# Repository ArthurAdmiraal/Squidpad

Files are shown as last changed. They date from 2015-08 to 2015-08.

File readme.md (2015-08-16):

# Squidpad
### About
The squidpad is a Slim Quality Uncostly Intuitive Drawing Pad. These are all the source files. This is an open project, which I'm documenting on [hackaday.io](https://hackaday.io/project/7153-squidpad).

### Repository structure
All design files go in the `Project` folder. Any files just made for documentation, such as a diagram in GeoGebra, can be found in the `Documentation` folder.

In both folders, the `Design files` folder contains source files. In the `Documentation` folder, any diagrams of pictures are just in the top-level folder. In the `Project` folder however, files generated using the design software, such as gerber files, can be found in the `Manifacturing` folder. People that just want to have a look at the board can find pdf's and OSHpark renders in the `Easily viewable` folder.

### License
All files in the `Project` folder are licensed under the [Creative Commons Attribution-NonCommercial-ShareAlike 4.0 International](http://creativecommons.org/licenses/by-nc-sa/4.0/) license. Everything in the `Documentation` folder can be used under the [Creative Commons Attribution-ShareAlike 4.0 International](http://creativecommons.org/licenses/by-sa/4.0/) license.

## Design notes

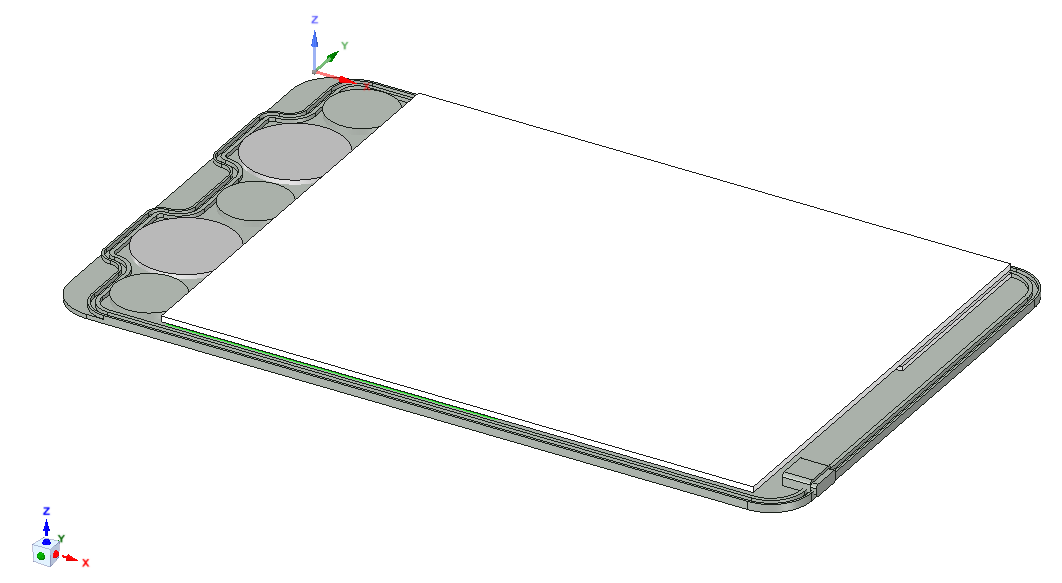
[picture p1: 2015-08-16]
Project/Easily viewable/MockupMechanical.png

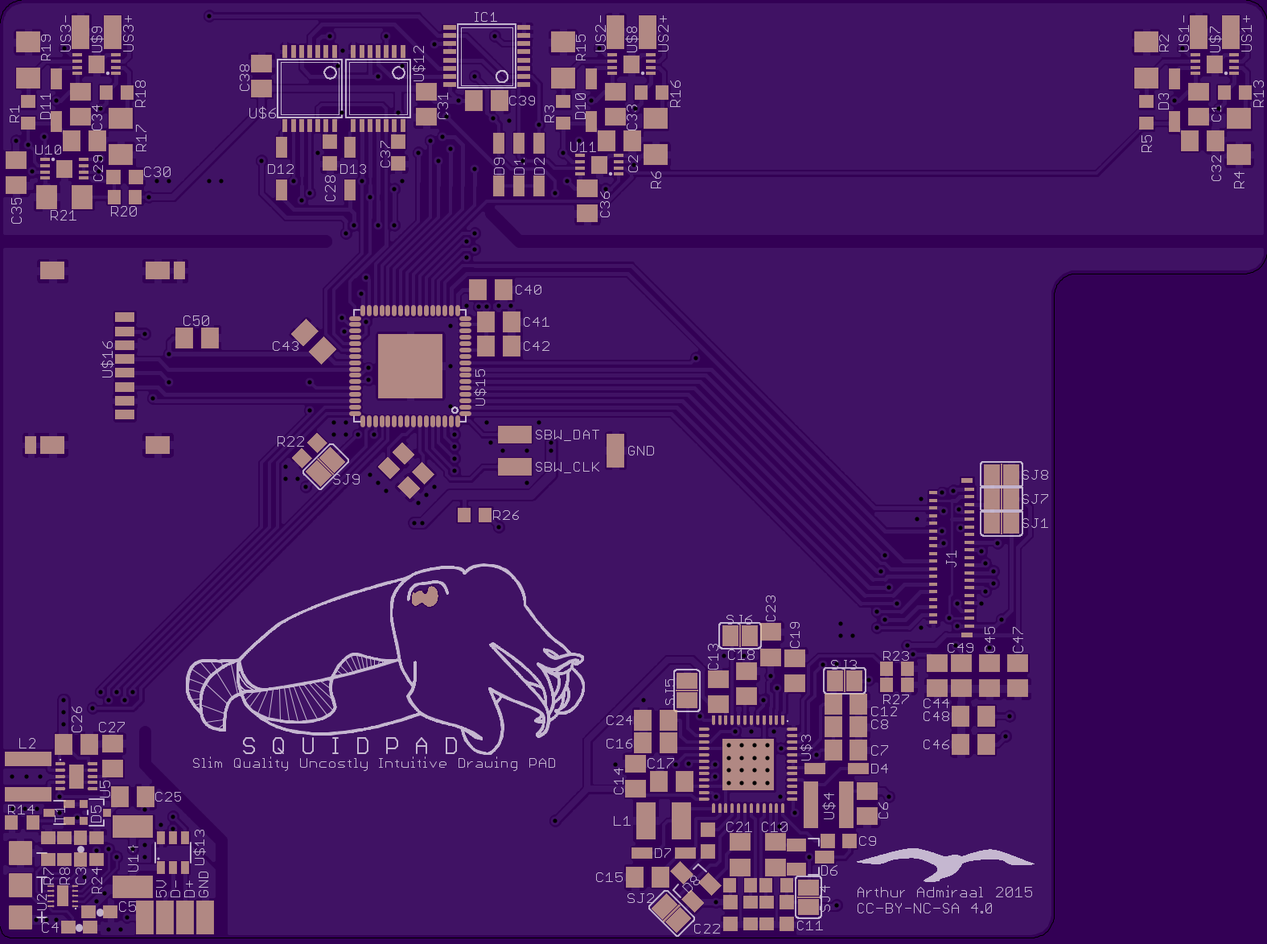
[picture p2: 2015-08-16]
Project/Easily viewable/SquidpadOSHparkRenderTop.png

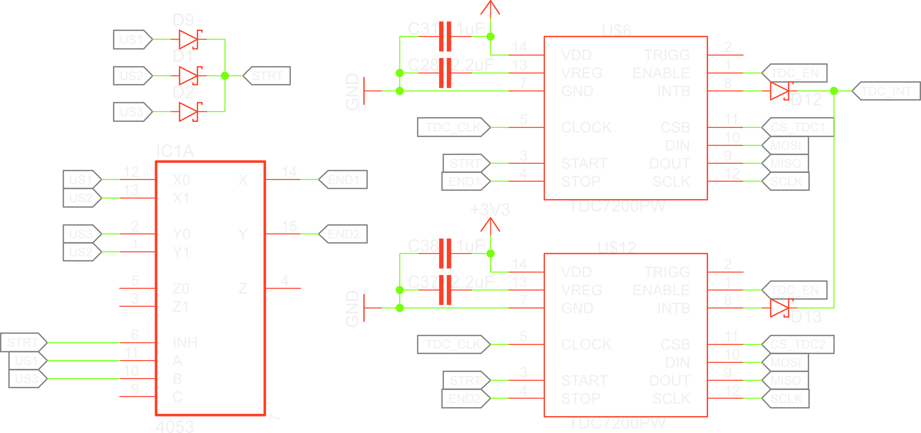
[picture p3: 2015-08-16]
Documentation/MicSwitching.png

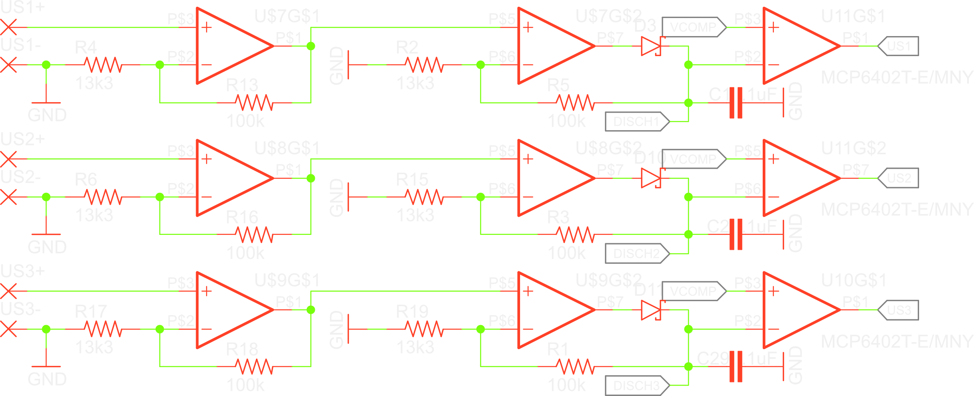
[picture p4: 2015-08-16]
Documentation/MicAmp.png

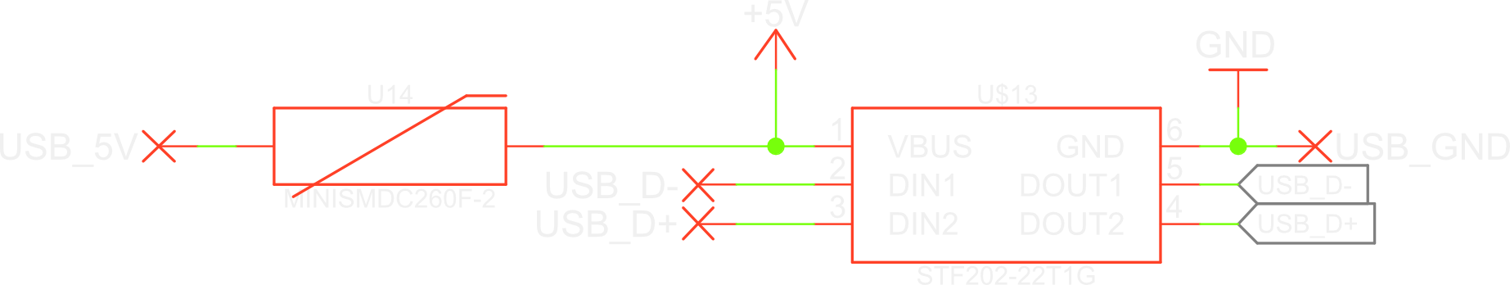
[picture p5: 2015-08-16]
Documentation/InputProtection.png

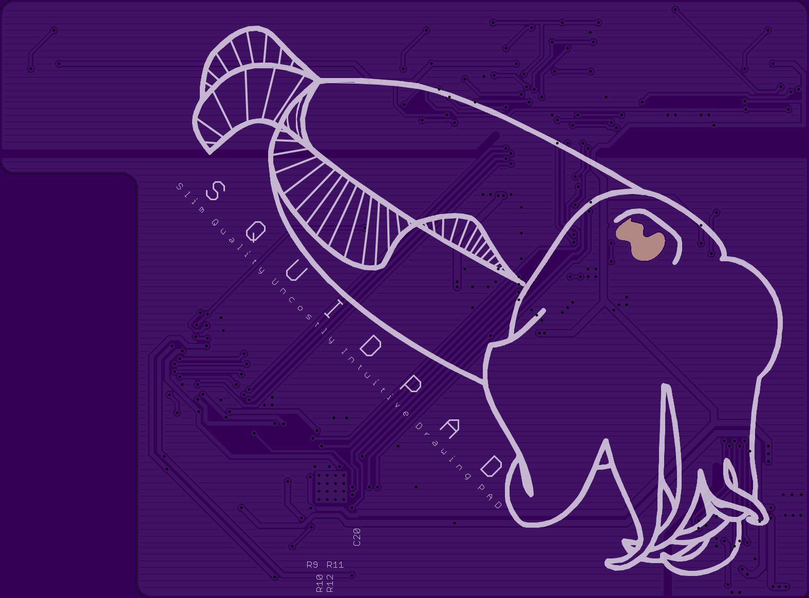
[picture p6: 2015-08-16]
Project/Easily viewable/SquidpadOSHparkRenderBottom.png

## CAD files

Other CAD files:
Documentation/Design files/MaterialsTest.blend

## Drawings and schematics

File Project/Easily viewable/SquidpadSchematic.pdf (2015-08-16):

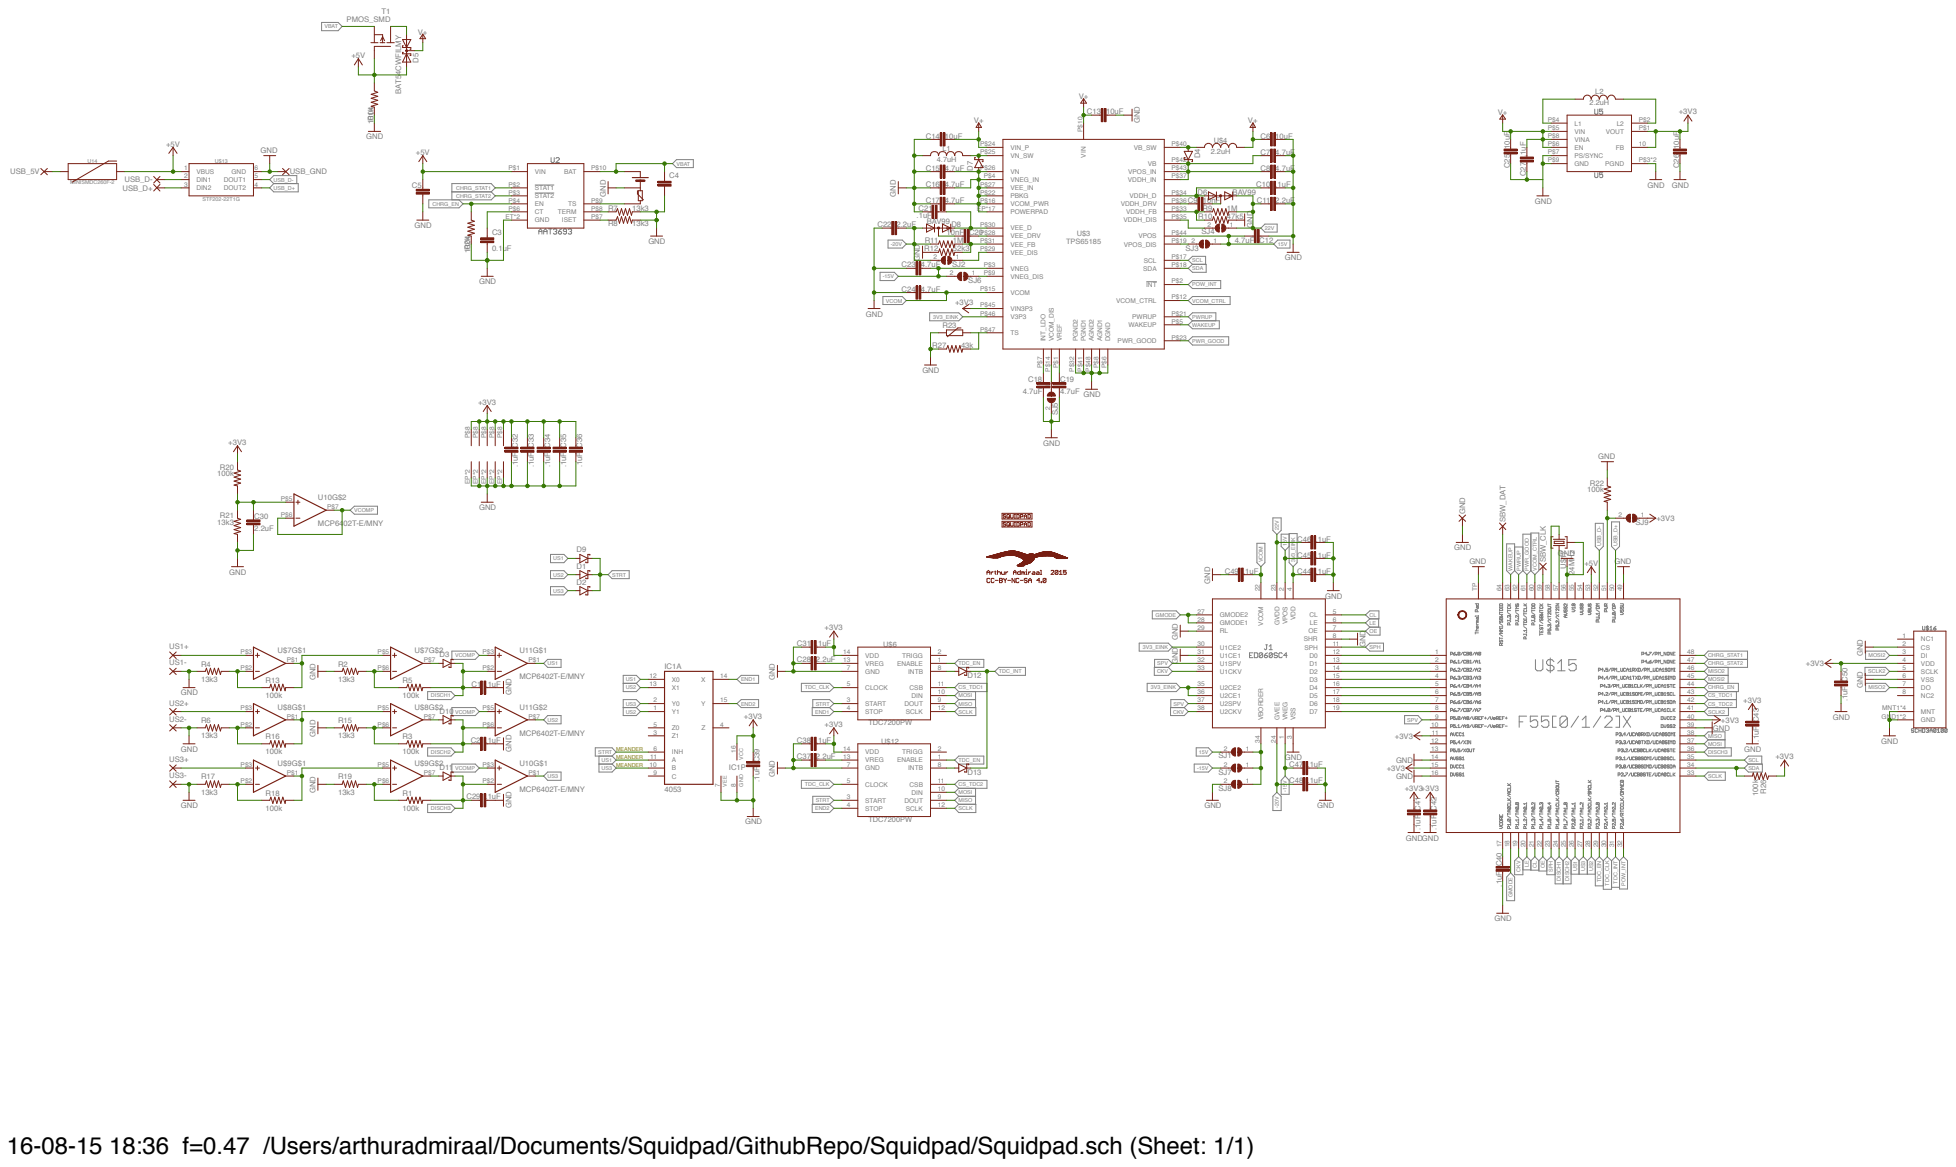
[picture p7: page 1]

16-08-15 18:36 f=0.47 /Users/arthuradmiraal/Documents/Squidpad/GithubRepo/Squidpad/Squidpad.sch (Sheet: 1/1)

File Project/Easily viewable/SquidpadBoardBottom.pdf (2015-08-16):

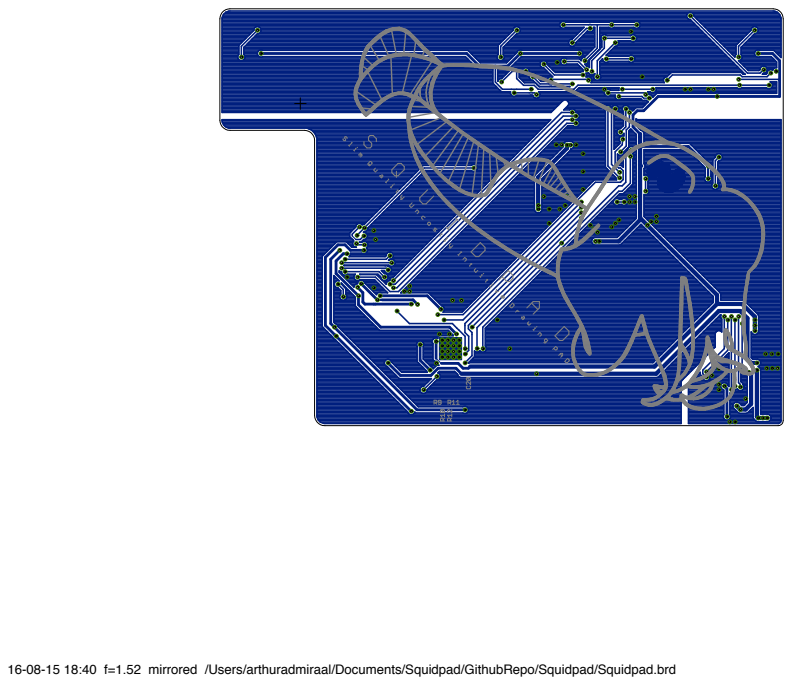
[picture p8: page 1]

16-08-15 18:40 f=1.52 mirrored /Users/arthuradmiraal/Documents/Squidpad/GithubRepo/Squidpad/Squidpad.brd

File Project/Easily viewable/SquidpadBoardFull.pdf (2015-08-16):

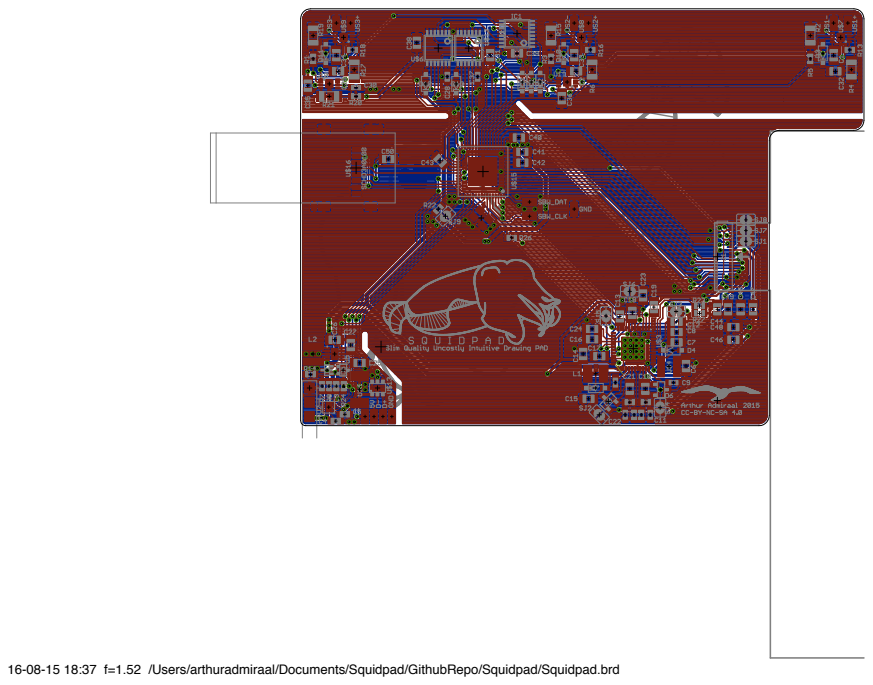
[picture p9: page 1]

16-08-15 18:37 f=1.52 /Users/arthuradmiraal/Documents/Squidpad/GithubRepo/Squidpad/Squidpad.brd

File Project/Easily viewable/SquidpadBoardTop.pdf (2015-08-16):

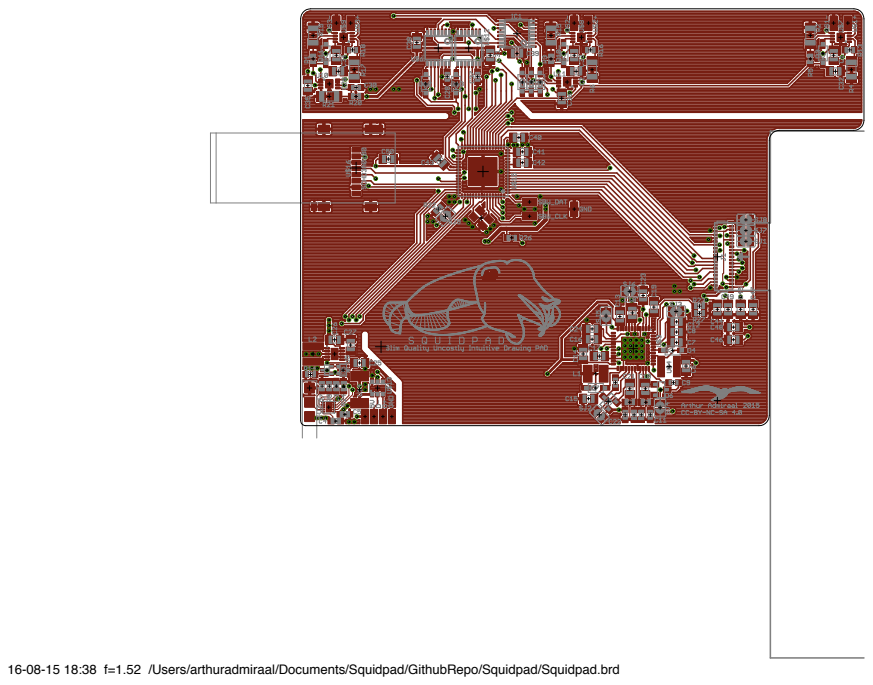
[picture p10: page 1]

16-08-15 18:38 f=1.52 /Users/arthuradmiraal/Documents/Squidpad/GithubRepo/Squidpad/Squidpad.brd

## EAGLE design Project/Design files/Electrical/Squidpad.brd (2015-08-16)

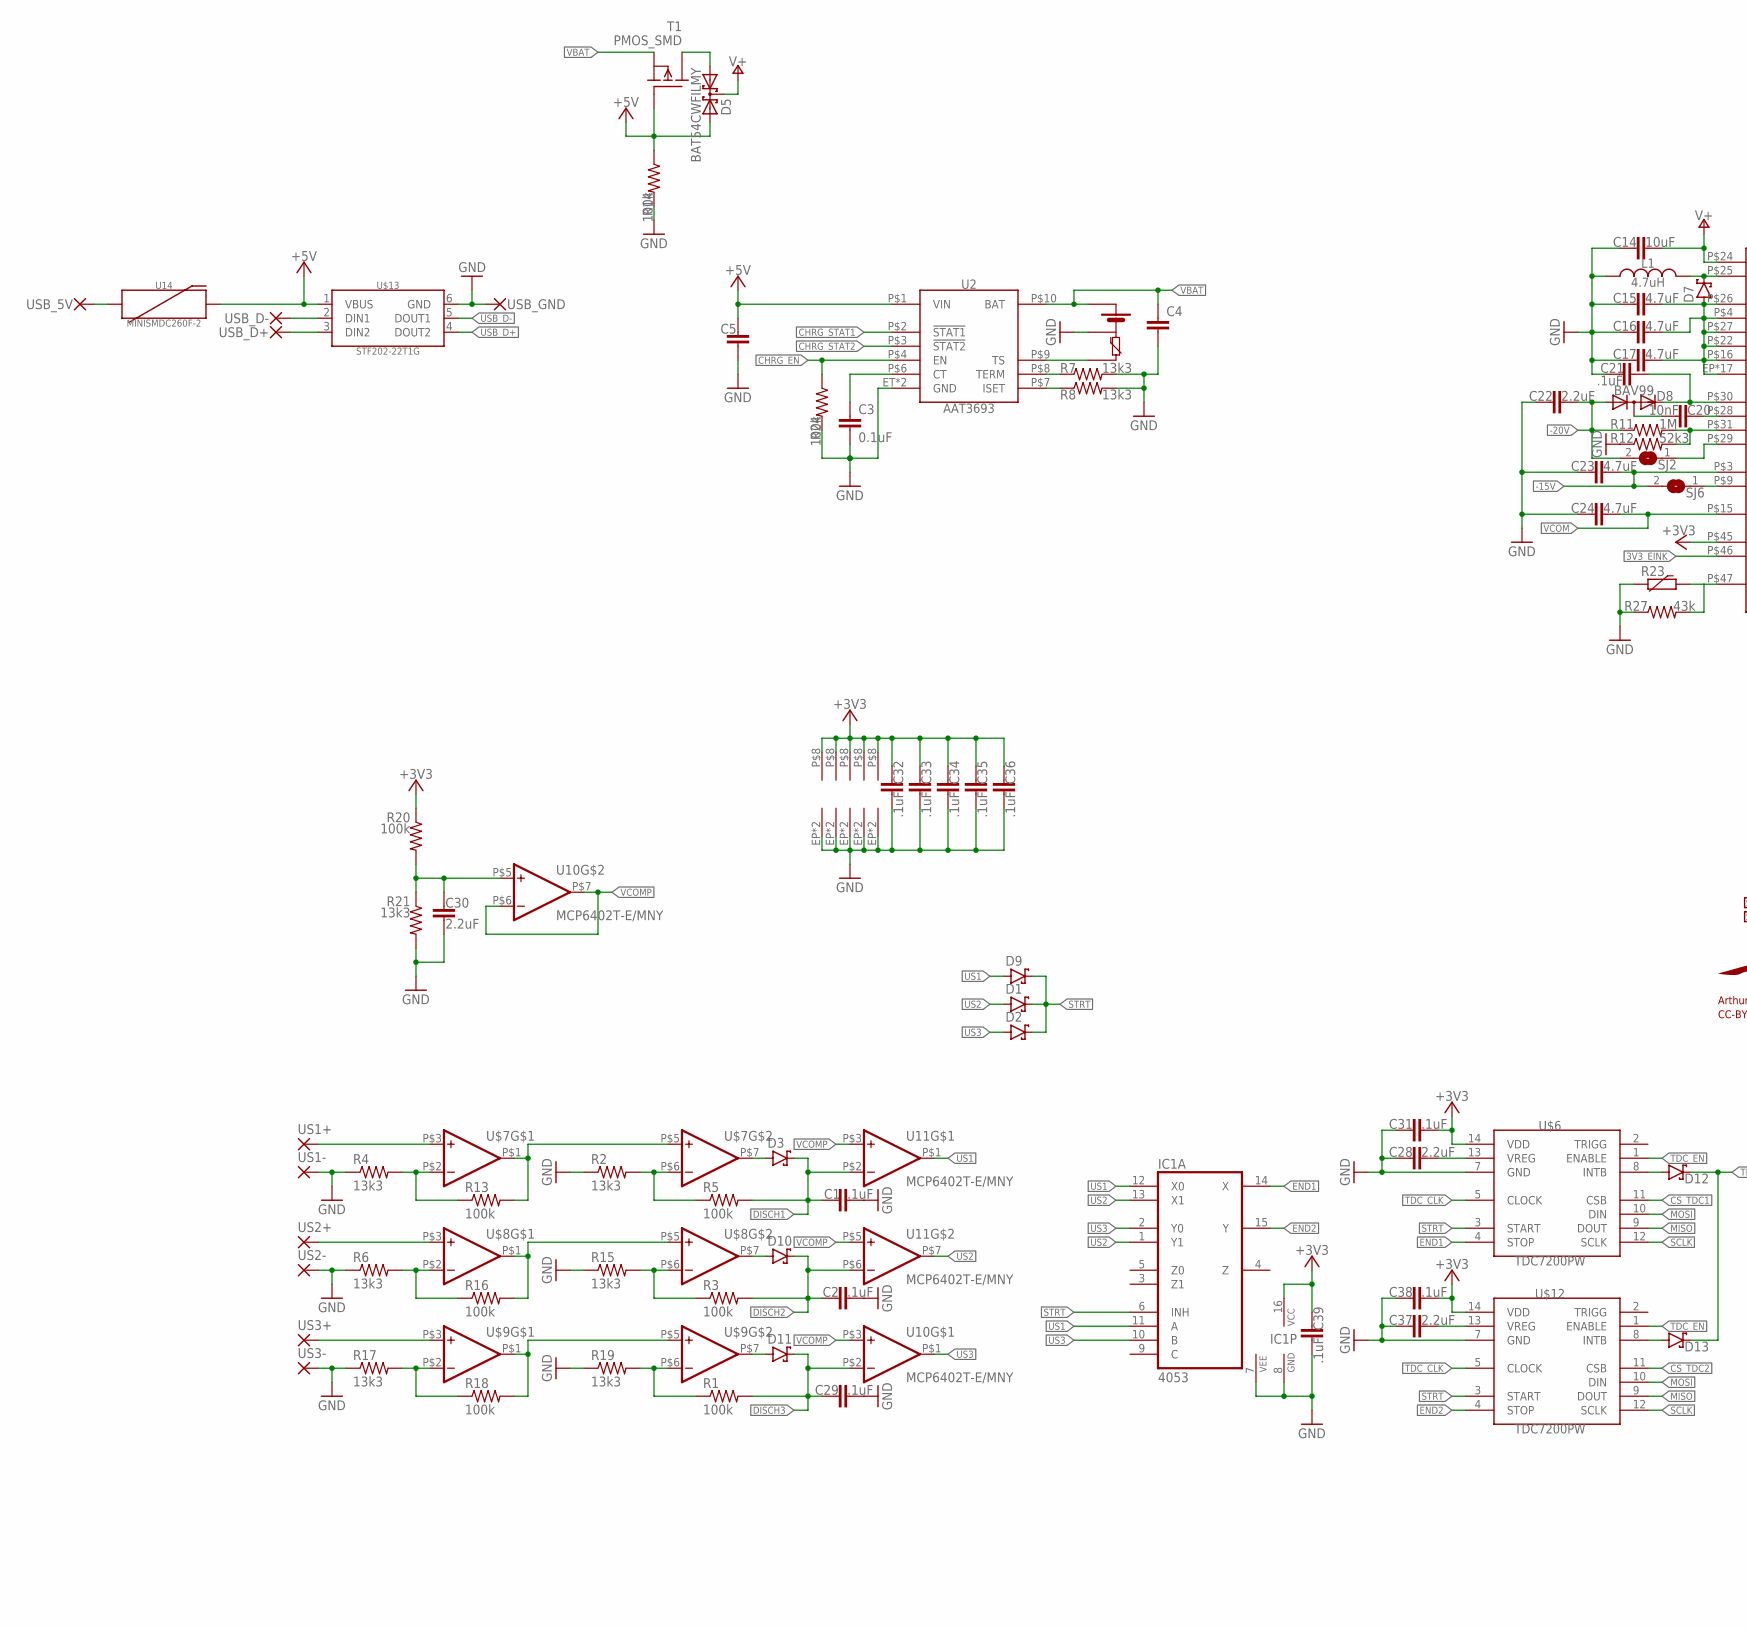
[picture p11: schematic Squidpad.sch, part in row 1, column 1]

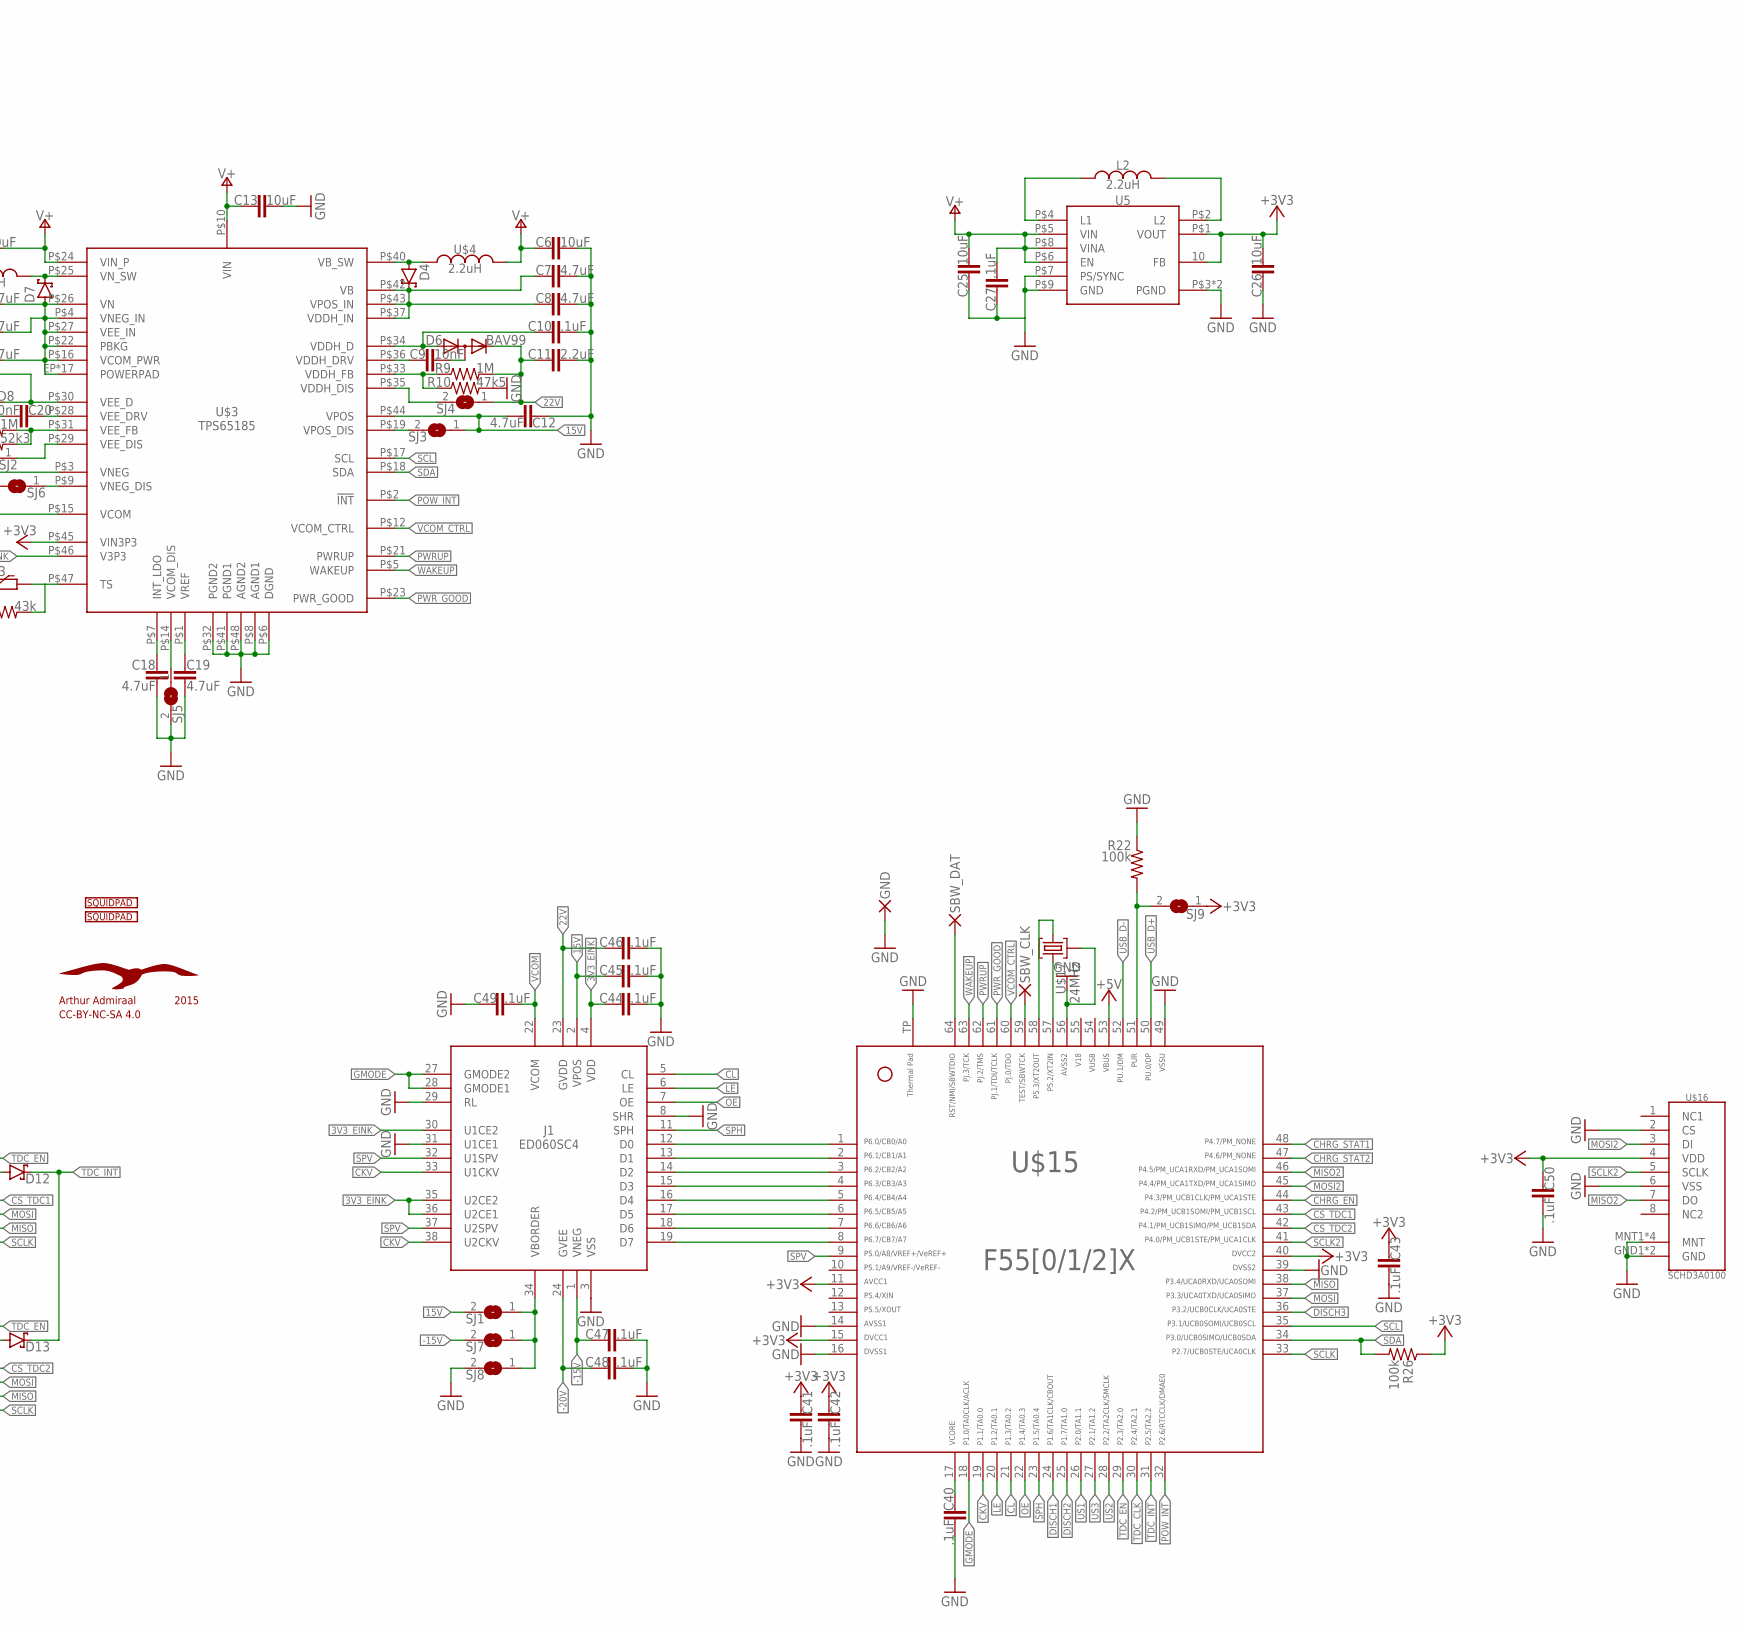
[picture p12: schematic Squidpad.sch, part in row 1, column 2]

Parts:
C1, C2, C10, C21, C27, C29, C31, C32, C33, C34, C35, C36, C38, C39, C40, C41, C42, C43, C44, C45, C46, C47, C48, C49, C50: .1uF; C0805K
C3: 0.1uF; 0603-CAP
C4, C5: CAP0603-CAP; 0603-CAP
C6, C13, C14, C25, C26: 10uF; C0805K
C7, C8, C12, C15, C16, C17, C18, C19, C23, C24: 4.7uF; C0805K
C9, C20: 10nF; C0603K
C11, C22, C28, C30, C37: 2.2uF; C0603K
D1, D2, D3, D4, D7, D9, D10, D11, D12, D13: MBR130T3G; SOD123
D5: BAT54CWFILMY; SOT323
D6, D8: BAV99; SOT23
GND: SMD2; SMD1,27-2,54
IC1: 4053; TSSOP16
J1: ED060SC4; FH26-39S-0.3SHW(05)
L1: 4.7uH; LQH44P
L2: 2.2uH; NR4012
R1, R3, R5, R13, R14, R16, R18, R20, R22, R24, R26: 100k; R0603
R2, R4, R6, R15, R17, R19, R21: 13k3; R1206
R7, R8: 13k3; R0603
R9, R11: 1M; R0603
R10: 47k5; R0603
R12: 52k3; R0603
R23: R-EU_R0603; R0603
R27: 43k; R0603
SBW_CLK: SMD2; SMD1,27-2,54
SBW_DAT: SMD2; SMD1,27-2,54
SJ1, SJ2, SJ3, SJ4, SJ5, SJ6, SJ7, SJ8, SJ9: SJ
T1: PMOS_SMD; SOT323R_INFINEON
U2: AAT3693; TDFN14
U5: TPS63031; R-PWSON-N10
U10, U11: MCP6402T-E/MNY; TFDN8
U14: MINISMDC260F-2
U$1: IPOD_NANO_5_BATTERY
U$2: SQUIDPAD_LOGOSQUIDPAD_LOGO_SMALL; SQUIDPAD_LOGO_LOWPOLY_SMALL
U$3: TPS65185; VQFN48
U$4: 2.2uH; NR4012
U$5: SQUIDPAD_LOGOSQUIDPAD_LOGO; SQUIDPAD_LOGO_LOWPOLY
U$6, U$12: TDC7200PW; TSSOP14
U$7, U$8, U$9: MCP6402T-E/MNY; TFDN8
U$10: AALECTRONICS_SEAGULL
U$13: STF202-22T1G; SOT23-6
U$15: F55[0/1/2]X---RGC64; RGC64
U$16: SCHD3A0100
U$17: 24MHz; TSX-3225
US1+, US1-, US2+, US2-, US3+, US3-: SMD2; SMD1,27-2,54
USB_5V: SMD2; SMD1,27-2,54
USB_D+: SMD2; SMD1,27-2,54
USB_D-: SMD2; SMD1,27-2,54
USB_GND: SMD2; SMD1,27-2,54

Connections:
3V3: C6.1, C13.1, C14.2, C25.2, C27.2, D5.3 (C), U5.P$5 (VIN), U5.P$6 (EN), U5.P$8 (VINA), U$3.P$10 (VIN), U$3.P$24 (VIN_P), U$4.P$2
3V3_EINK: C44.1, J1.4 (VDD), J1.30 (U1CE2), J1.35 (U2CE2), J1.36 (U2CE1), U$3.P$46 (V3P3)
15V: C12.2, C45.1, J1.2 (VPOS), SJ1.2, SJ3.1, U$3.P$44 (VPOS)
22V: C11.1, C46.1, D6.2 (C), J1.23 (GVDD), R9.2, SJ4.1
54: U$15.54
55: U$15.55
+3V3: C26.2, C31.2, C32.1, C33.1, C34.1, C35.1, C36.1, C38.2, C39.1, C41.1, C42.1, C43.1, C50.1, IC1.16 (VCC), R20.1, R26.1, SJ9.1, U5.10 (FB), U5.P$1 (VOUT), U10.P$8 (V+), U11.P$8 (V+), U$3.P$45 (VIN3P3), U$6.14 (VDD), U$7.P$8 (V+), U$8.P$8 (V+), U$9.P$8 (V+), U$12.14 (VDD), U$15.11, U$15.15, U$15.40, U$16.4 (VDD)
+5V: C5.1, D5.2 (A2), R14.1, T1.1 (G), U2.P$1 (VIN), U14.P$2, U$13.1 (VBUS), U$15.53
-15V: C23.2, C47.1, J1.1 (VNEG), SJ6.2, SJ7.2, U$3.P$3 (VNEG)
-20V: C22.2, C48.1, D8.1 (A), J1.24 (GVEE), R11.1, SJ2.2
CHRG_EN: R24.1, U2.P$4 (EN), U$15.44
CHRG_STAT1: U2.P$2 (!STAT1), U$15.48
CHRG_STAT2: U2.P$3 (!STAT2), U$15.47
CKV: J1.33 (U1CKV), J1.38 (U2CKV), U$15.19
CL: J1.5 (CL), U$15.21
CS_TDC1: U$6.11 (CSB), U$15.43
CS_TDC2: U$12.11 (CSB), U$15.42
D0: J1.12 (D0), U$15.1
D1: J1.13 (D1), U$15.2
D2: J1.14 (D2), U$15.3
D3: J1.15 (D3), U$15.4
D4: J1.16 (D4), U$15.5
D5: J1.17 (D5), U$15.6
D6: J1.18 (D6), U$15.7
D7: J1.19 (D7), U$15.8
DISCH1: C1.1, D3.1 (C), R5.2, U11.P$2 (-IN), U$15.24
DISCH2: C2.1, D10.1 (C), R3.2, U11.P$6 (-IN), U$15.25
DISCH3: C29.1, D11.1 (C), R1.2, U10.P$2 (-IN), U$15.36
END1: IC1.14 (X), U$6.4 (STOP)
END2: IC1.15 (Y), U$12.4 (STOP)
GMODE: J1.27 (GMODE2), J1.28 (GMODE1), U$15.18
GND: C1.2, C2.2, C3.2, C4.2, C5.2, C6.2, C7.2, C8.2, C10.2, C11.2, C12.1, C13.2, C14.1, C15.1, C16.1, C17.1, C18.1, C19.1, C21.1, C22.1, C23.1, C24.1, C25.1, C26.1, C27.1, C28.1, C29.2, C30.2, C31.1, C32.2, C33.2, C34.2, C35.2, C36.2, C37.1, C38.1, C39.2, C40.2, C41.2, C42.2, C43.2, C44.2, C45.2, C46.2, C47.2, C48.2, C49.1, C50.2, GND.1, IC1.7 (VEE), IC1.8 (GND), J1.3 (VSS), J1.8 (SHR), J1.29 (RL), J1.31 (U1CE1), L1.P$1, R2.1, R4.1, R6.1, R7.2, R8.2, R10.2, R12.1, R14.2, R15.1, R17.1, R19.1, R21.2, R22.1, R23.1, R24.2, R27.1, SJ5.2, SJ8.2, U2.ET (GND), U2.P$5 (GND), U5.P$3 (PGND), U5.P$7 (PS/SYNC), U5.P$9 (GND), U5.POWERPAD (PGND), U10.EP (V-), U10.P$4 (V-), U11.EP (V-), U11.P$4 (V-), U$1.P- (BATTERY-), U$3.P$6 (DGND), U$3.P$8 (AGND1), U$3.P$32 (PGND2), U$3.P$41 (PGND1), U$3.P$48 (AGND2), U$6.7 (GND), U$7.EP (V-), U$7.P$4 (V-), U$8.EP (V-), U$8.P$4 (V-), U$9.EP (V-), U$9.P$4 (V-), U$12.7 (GND), U$13.6 (GND), U$15.14, U$15.16, U$15.39, U$15.49, U$15.56, U$15.TP, U$16.2 (CS), U$16.6 (VSS), U$16.GND1 (GND), U$16.GND2 (GND), U$16.MNT1 (MNT), U$16.MNT2 (MNT), U$16.MNT3 (MNT), U$16.MNT4 (MNT), U$17.2, U$17.3 (2), US1-.1, US2-.1, US3-.1, USB_GND.1
LE: J1.6 (LE), U$15.20
MISO: U$6.9 (DOUT), U$12.9 (DOUT), U$15.38
MISO2: U$15.46, U$16.7 (DO)
MOSI: U$6.10 (DIN), U$12.10 (DIN), U$15.37
MOSI2: U$15.45, U$16.3 (DI)
unnamed: U$7.P$3 (+IN), US1+.1
unnamed: R2.2, R5.1, U$7.P$6 (-IN)
unnamed: D12.2 (A), U$6.8 (INTB)
unnamed: U$8.P$3 (+IN), US2+.1
unnamed: R6.2, R16.1, U$8.P$2 (-IN)
unnamed: R16.2, U$8.P$1 (OUT), U$8.P$5 (+IN)
unnamed: D4.2 (A), U$3.P$40 (VB_SW), U$4.P$1
unnamed: U2.P$9 (TS), U$1.TH (TEMP)
unnamed: U$13.3 (DIN2), USB_D+.1
unnamed: U$13.2 (DIN1), USB_D-.1
unnamed: U$15.57, U$17.4 (3)
unnamed: R7.1, U2.P$8 (TERM)
unnamed: R8.1, U2.P$7 (ISET)
unnamed: C7.1, C8.1, D4.1 (C), U$3.P$37 (VDDH_IN), U$3.P$42 (VB), U$3.P$43 (VPOS_IN)
unnamed: D3.2 (A), U$7.P$7 (OUT)
unnamed: D13.2 (A), U$12.8 (INTB)
unnamed: C3.1, U2.P$6 (CT)
unnamed: C10.1, D6.1 (A), U$3.P$34 (VDDH_D)
unnamed: D5.1 (A1), T1.3 (D)
unnamed: C9.1, U$3.P$36 (VDDH_DRV)
unnamed: C9.2, D6.3 (AC)
unnamed: R9.1, R10.1, U$3.P$33 (VDDH_FB)
unnamed: C20.2, D8.3 (AC)
unnamed: D7.1 (C), L1.P$2, U$3.P$25 (VN_SW)
unnamed: C15.2, C16.2, C17.2, D7.2 (A), U$3.EP (POWERPAD), U$3.EP1 (POWERPAD), U$3.EP2 (POWERPAD), U$3.EP3 (POWERPAD), U$3.EP4 (POWERPAD), U$3.EP5 (POWERPAD), U$3.EP6 (POWERPAD), U$3.EP7 (POWERPAD), U$3.EP8 (POWERPAD), U$3.EP9 (POWERPAD), U$3.EP10 (POWERPAD), U$3.EP11 (POWERPAD), U$3.EP12 (POWERPAD), U$3.EP13 (POWERPAD), U$3.EP14 (POWERPAD), U$3.EP15 (POWERPAD), U$3.EP16 (POWERPAD), U$3.P$4 (VNEG_IN), U$3.P$16 (VCOM_PWR), U$3.P$22 (PBKG), U$3.P$26 (VN), U$3.P$27 (VEE_IN)
unnamed: C18.2, U$3.P$7 (INT_LDO)
unnamed: C19.2, U$3.P$1 (VREF)
unnamed: C21.2, D8.2 (C), U$3.P$30 (VEE_D)
unnamed: SJ6.1, U$3.P$9 (VNEG_DIS)
unnamed: L2.P$1, U5.P$4 (L1)
unnamed: C20.1, U$3.P$28 (VEE_DRV)
unnamed: R11.2, R12.2, U$3.P$31 (VEE_FB)
unnamed: SJ2.1, U$3.P$29 (VEE_DIS)
unnamed: SJ3.2, U$3.P$19 (VPOS_DIS)
unnamed: SJ4.2, U$3.P$35 (VDDH_DIS)
unnamed: SJ5.1, U$3.P$14 (VCOM_DIS)
unnamed: L2.P$2, U5.P$2 (L2)
unnamed: C28.2, U$6.13 (VREG)
unnamed: R4.2, R13.1, U$7.P$2 (-IN)
unnamed: R13.2, U$7.P$1 (OUT), U$7.P$5 (+IN)
unnamed: R3.1, R15.2, U$8.P$6 (-IN)
unnamed: U14.P$1, USB_5V.1
unnamed: U$9.P$3 (+IN), US3+.1
unnamed: R17.2, R18.1, U$9.P$2 (-IN)
unnamed: R18.2, U$9.P$1 (OUT), U$9.P$5 (+IN)
unnamed: R1.1, R19.2, U$9.P$6 (-IN)
unnamed: D10.2 (A), U$8.P$7 (OUT)
unnamed: D11.2 (A), U$9.P$7 (OUT)
unnamed: C37.2, U$12.13 (VREG)
unnamed: J1.34 (VBORDER), SJ1.1, SJ7.1, SJ8.1
unnamed: SBW_DAT.1, U$15.64
unnamed: SBW_CLK.1, U$15.59
unnamed: C40.1, U$15.17
unnamed: R22.2, SJ9.2, U$15.51
unnamed: U$15.58, U$17.1
unnamed: R23.2, R27.2, U$3.P$47 (TS)
OE: J1.7 (OE), U$15.22
POW_INT: U$3.P$2 (!INT), U$15.32
PWRUP: U$3.P$21 (PWRUP), U$15.62
PWR_GOOD: U$3.P$23 (PWR_GOOD), U$15.61
SCL: U$3.P$17 (SCL), U$15.35
SCLK: U$6.12 (SCLK), U$12.12 (SCLK), U$15.33
SCLK2: U$15.41, U$16.5 (SCLK)
SDA: R26.2, U$3.P$18 (SDA), U$15.34
SPH: J1.11 (SPH), U$15.23
SPV: J1.32 (U1SPV), J1.37 (U2SPV), U$15.9
STRT: D1.1 (C), D2.1 (C), D9.1 (C), IC1.6 (INH), U$6.3 (START), U$12.3 (START)
TDC_CLK: U$6.5 (CLOCK), U$12.5 (CLOCK), U$15.30
TDC_EN: U$6.1 (ENABLE), U$12.1 (ENABLE), U$15.29
TDC_INT: D12.1 (C), D13.1 (C), U$15.31
US1: D9.2 (A), IC1.11 (A), IC1.12 (X0), U11.P$1 (OUT), U$15.26
US2: D1.2 (A), IC1.1 (Y1), IC1.13 (X1), U11.P$7 (OUT), U$15.28
US3: D2.2 (A), IC1.2 (Y0), IC1.10 (B), U10.P$1 (OUT), U$15.27
USB_D+: U$13.4 (DOUT2), U$15.50
USB_D-: U$13.5 (DOUT1), U$15.52
VBAT: C4.1, T1.2 (S), U2.P$10 (BAT), U$1.P+ (BATTERY+)
VCOM: C24.2, C49.2, J1.22 (VCOM), U$3.P$15 (VCOM)
VCOMP: U10.P$3 (+IN), U10.P$6 (-IN), U10.P$7 (OUT), U11.P$3 (+IN), U11.P$5 (+IN)
VCOMP_BEFORE: C30.1, R20.2, R21.1, U10.P$5 (+IN)
VCOM_CTRL: U$3.P$12 (VCOM_CTRL), U$15.60
WAKEUP: U$3.P$5 (WAKEUP), U$15.63

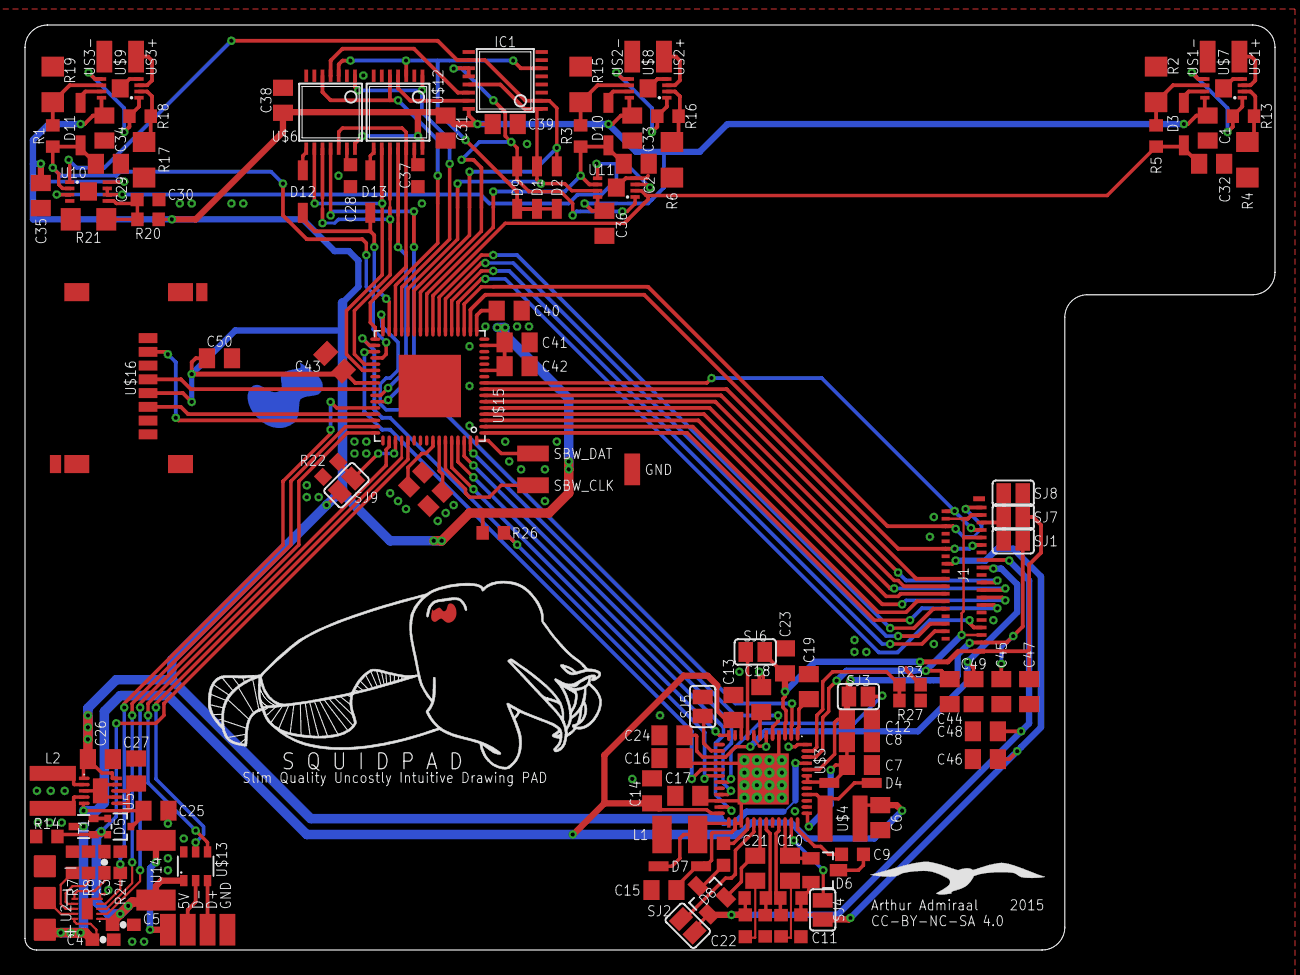
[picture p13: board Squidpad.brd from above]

Board: 2 copper layers, 100.0 x 74.0 mm, 136 parts (1 on the bottom side), 116 nets.

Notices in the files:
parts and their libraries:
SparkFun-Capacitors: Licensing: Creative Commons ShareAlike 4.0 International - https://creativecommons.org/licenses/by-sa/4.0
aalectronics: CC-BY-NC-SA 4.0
